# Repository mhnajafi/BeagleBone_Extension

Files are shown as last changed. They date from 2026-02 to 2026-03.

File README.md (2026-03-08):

# BeagleBone PLC Extension

This project focuses on transforming a BeagleBone Black into a Programmable Logic Controller (PLC) capable system. It includes PCB designs for Digital Input (DI), Digital Output (DO), and a Main Carrier board, along with simulation files.

## Project Structure

The repository is organized as follows:

- **PCB Design** (`PCB/`)
    - **Main/**: Contains the Altium Designer project files for the main carrier board that interfaces with the BeagleBone Black headers (P8/P9).
    - **DI/**: Design files for the Digital Input module.
    - **DO/**: Design files for the Digital Output module.

- **Simulation** (`DIO Simulate/`)
    - Contains Proteus simulation files (`.pdsprj`) to simulate the Digital I/O behavior before hardware implementation.

## Key Features

- **Modular Design**: Separate modules for Inputs and Outputs allowing for scalable IO.
- **BeagleBone Integration**: Designed to mount directly or interface via ribbon cables to the BeagleBone P8 and P9 headers.
- **Industrial Readiness**: Aimed at providing robust IO suitable for industrial control applications.

## Usage

1. **Hardware**: Start by reviewing the `PCB/Main` schematics. The manufacturing files (Gerbers) can be generated from the `.PcbDoc` files using Altium Designer.
2. **Simulation**: Open `DIO Simulate/DIO.pdsprj` in Proteus Design Suite to view and run the logic simulation.
3. **Reference**: Consult the pinout images in `Ignore/Doc/` when programming the IO pins on the BeagleBone.

## Gallery

### Main Carrier Board
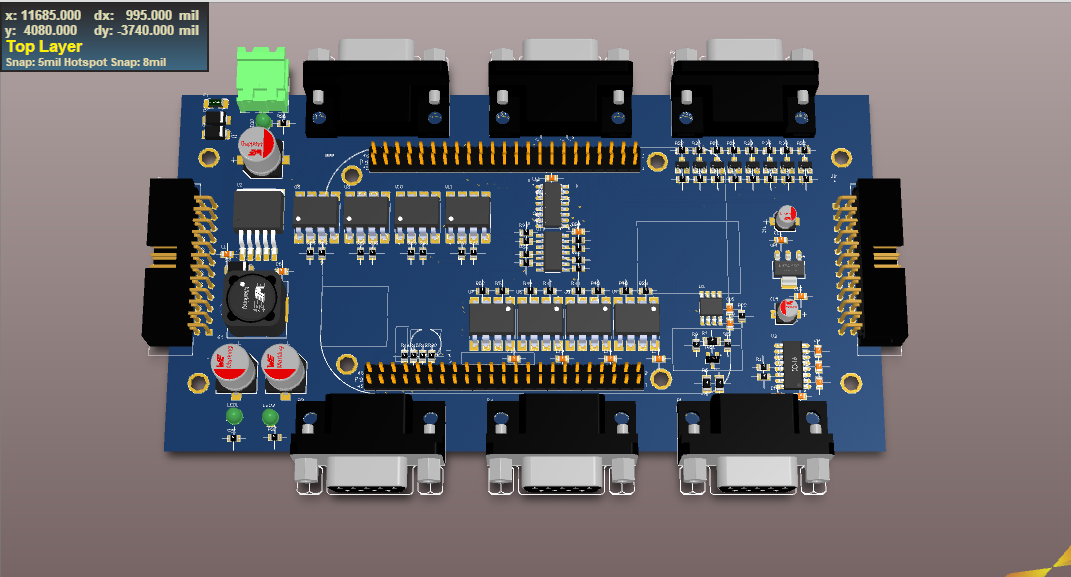
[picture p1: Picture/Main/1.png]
Main Board 1

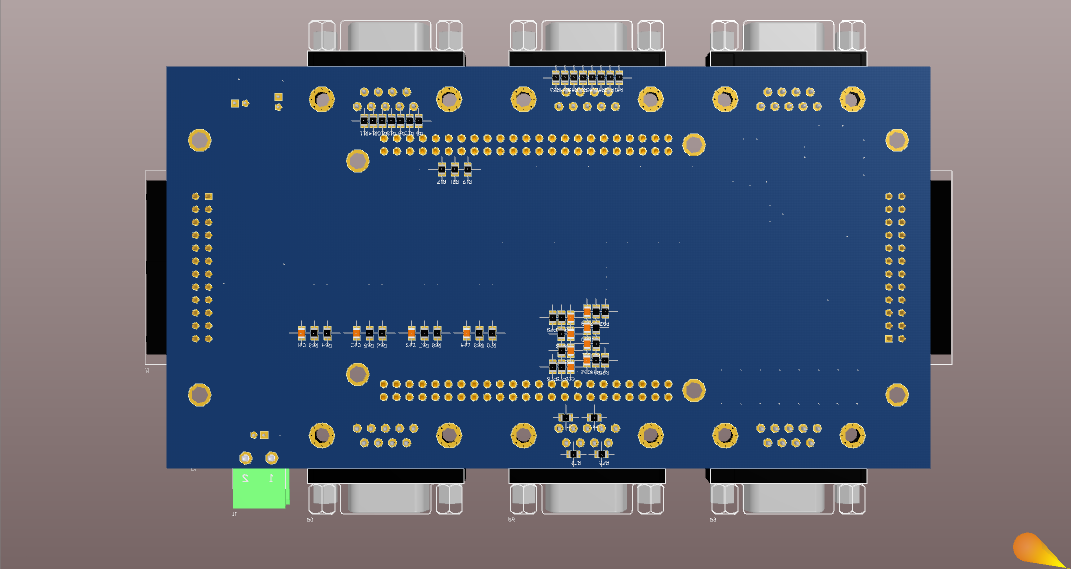
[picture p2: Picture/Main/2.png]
Main Board 2

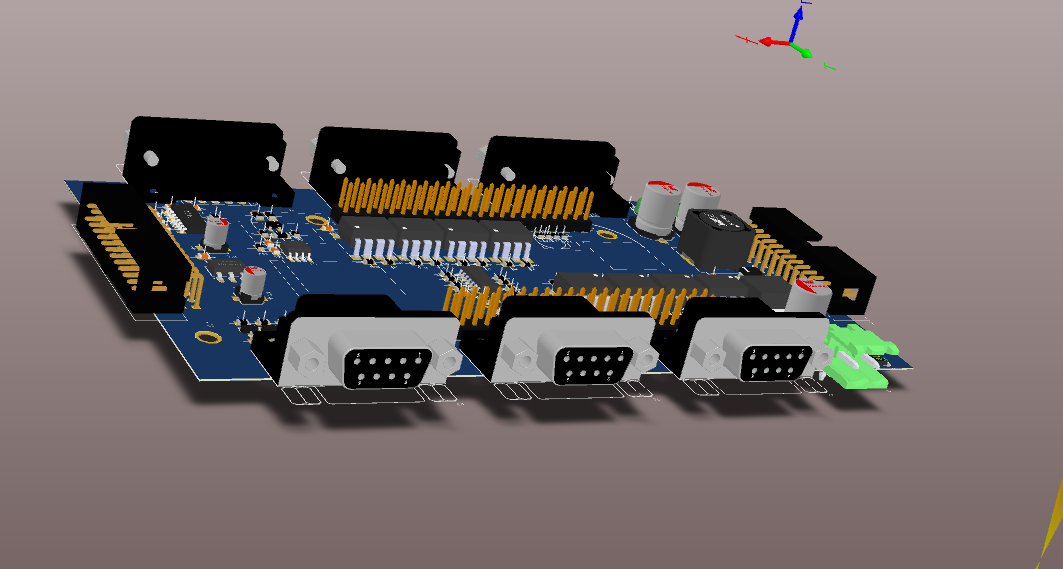
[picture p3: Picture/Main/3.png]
Main Board 3


### Digital Input Module
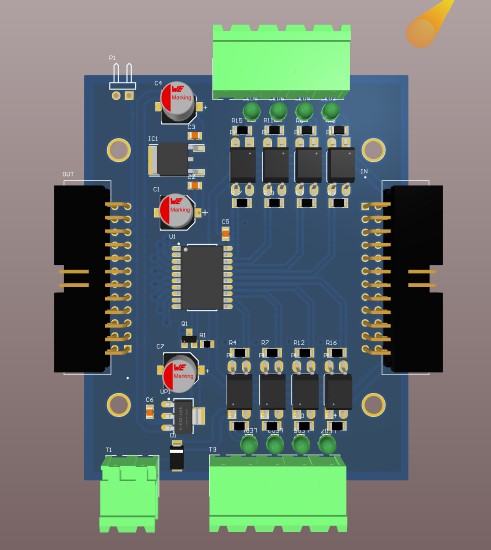
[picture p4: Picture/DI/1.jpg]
DI Module 1

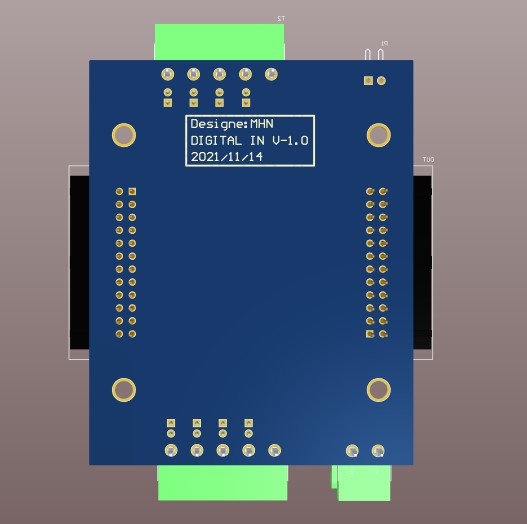
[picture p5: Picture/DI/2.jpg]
DI Module 2

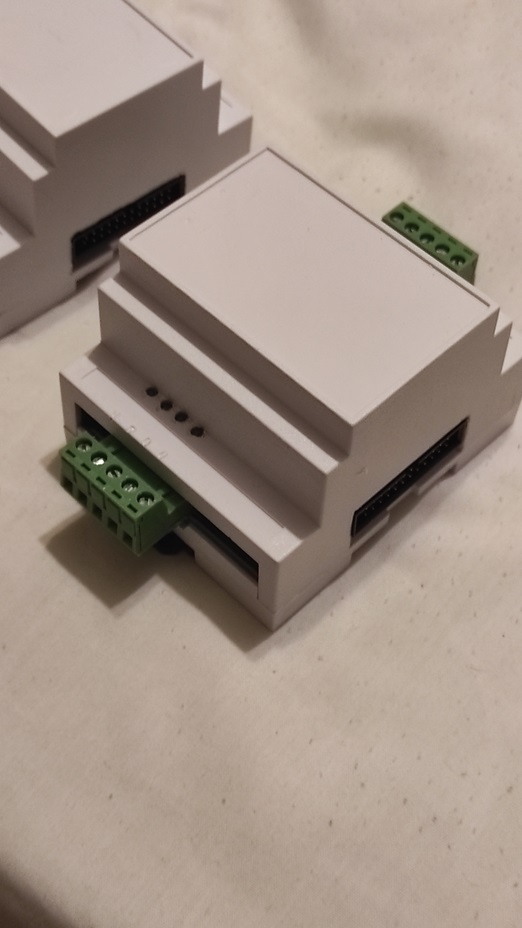
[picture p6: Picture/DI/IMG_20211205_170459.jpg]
DI Module Real


### Digital Output Module
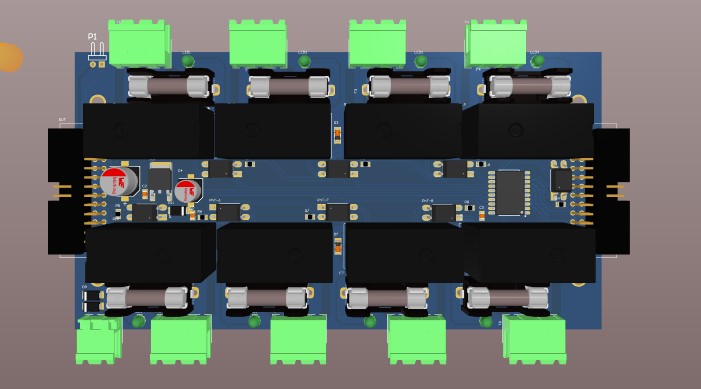
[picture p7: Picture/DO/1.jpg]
DO Module 1

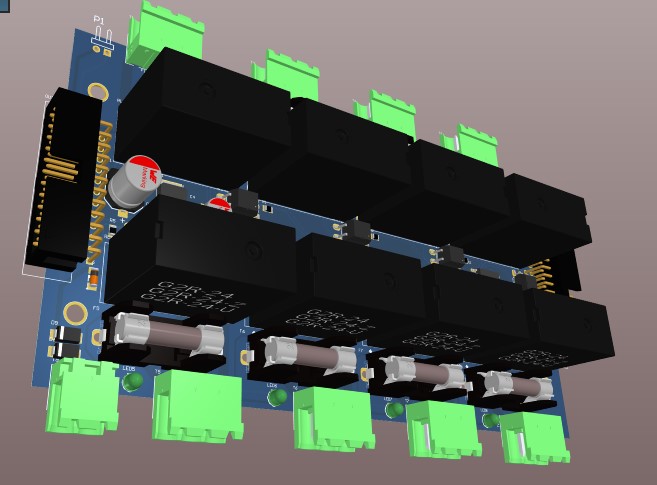
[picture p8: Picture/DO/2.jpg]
DO Module 2

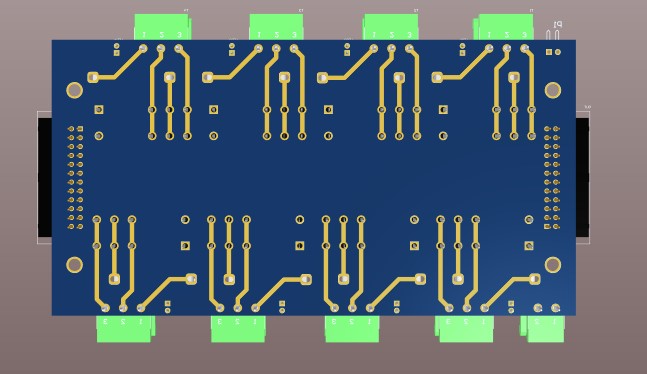
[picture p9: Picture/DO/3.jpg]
DO Module 3


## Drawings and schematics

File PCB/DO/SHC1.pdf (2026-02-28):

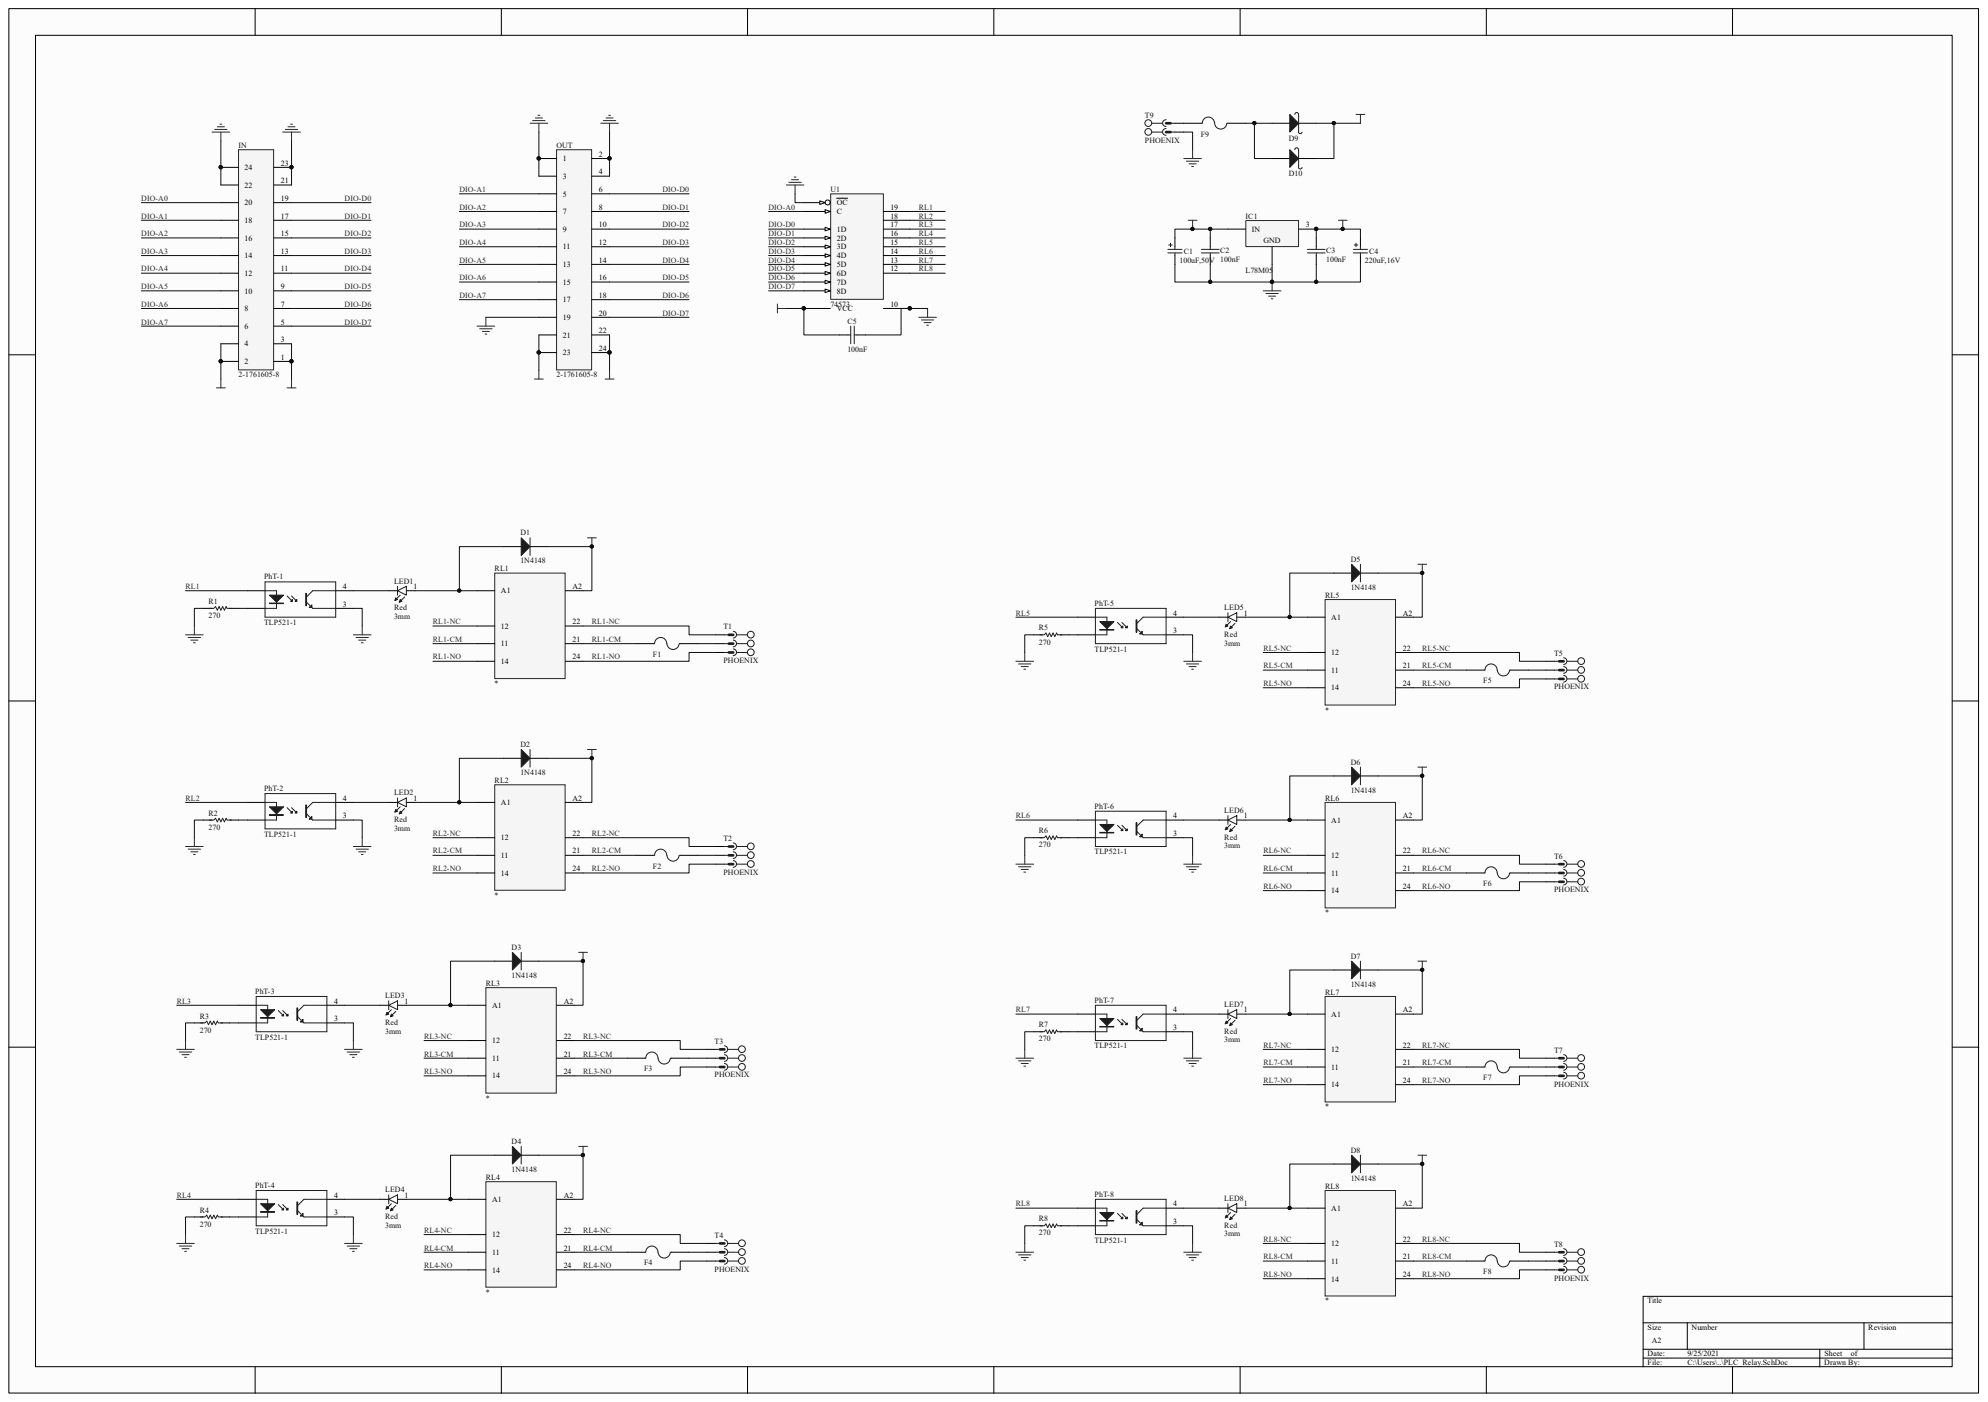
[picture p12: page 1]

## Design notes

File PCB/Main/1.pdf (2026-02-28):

# Beagle Bone Black

Expansion_Left | Expansion_Right

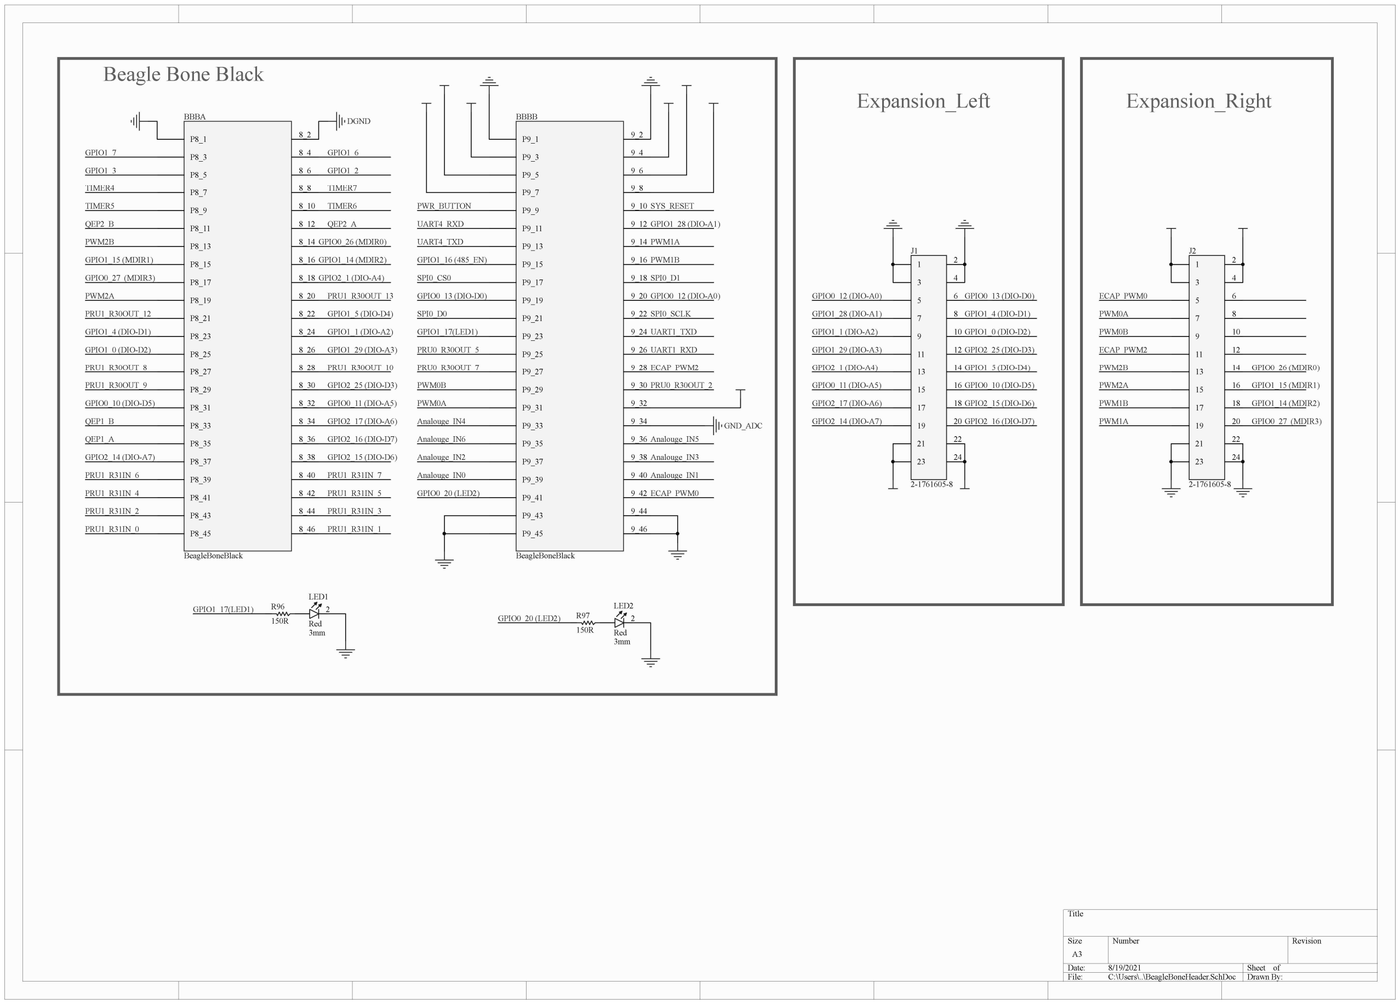
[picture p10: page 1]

Title

Size | Number | Revision
A3
Date: | 8/19/2021 | Sheet of
File: | C:\Users\..\BeagleBoneHeader.SchDoc | Drawn By:
P8_1 | 8_2
P8_3 | 8_4
P8_5 | 8_6
P8_7 | 8_8
P8_9 | 8_10
P8_11 | 8_12
P8_13 | 8_14
P8_15 | 8_16
P8_17 | 8_18
P8_19 | 8_20
P8_21 | 8_22
P8_23 | 8_24
P8_25 | 8_26
P8_27 | 8_28
P8_29 | 8_30
P8_31 | 8_32
P8_33 | 8_34
P8_35 | 8_36
P8_37 | 8_38
P8_39 | 8_40
P8_41 | 8_42
P8_43 | 8_44
P8_45 | 8_46

BBBA

BeagleBoneBlack

DGND

TIMER4

TIMER5

QEP2_B

PWM2B

PWM2A

PRU1_R30OUT_12

PRU1_R30OUT_8

PRU1_R30OUT_9

QEP1_B

QEP1_A

PRU1_R31IN_6

PRU1_R31IN_4

PRU1_R31IN_2

PRU1_R31IN_0

TIMER7

TIMER6

QEP2_A

PRU1_R30OUT_13

PRU1_R30OUT_10

PRU1_R31IN_7

PRU1_R31IN_5

PRU1_R31IN_3

PRU1_R31IN_1

P9_1 | 9_2
P9_3 | 9_4
P9_5 | 9_6
P9_7 | 9_8
P9_9 | 9_10
P9_11 | 9_12
P9_13 | 9_14
P9_15 | 9_16
P9_17 | 9_18
P9_19 | 9_20
P9_21 | 9_22
P9_23 | 9_24
P9_25 | 9_26
P9_27 | 9_28
P9_29 | 9_30
P9_31 | 9_32
P9_33 | 9_34
P9_35 | 9_36
P9_37 | 9_38
P9_39 | 9_40
P9_41 | 9_42
P9_43 | 9_44
P9_45 | 9_46

BBBB

BeagleBoneBlack

PWR_BUTTON

UART4_RXD

UART4_TXD

GPIO1_16 (485_EN)

SPI0_CS0

SPI0_D0

PRU0_R30OUT_5

PRU0_R30OUT_7

PWM0B

PWM0A

Analouge_IN4

Analouge_IN6

Analouge_IN2

Analouge_IN0

SYS_RESET

PWM1B

ECAP_PWM2

PRU0_R30OUT_2

Analouge_IN1

ECAP_PWM0

PWM1A

SPI0_D1

UART1_TXD

UART1_RXD

SPI0_SCLK

Analouge_IN5

Analouge_IN3

GND_ADC

GPIO1_7

GPIO1_3

GPIO1_6

GPIO1_2

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
11 12

13 14

15 16

17 18

19 20

21 22

23 24

J1

2-1761605-8

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
11 12

13 14

15 16

17 18

19 20

21 22

23 24

J2

2-1761605-8

PWM1A

PWM1B

GPIO1_17(LED1)

ECAP_PWM2

PWM0B

PWM0A

ECAP_PWM0

PWM2B

PWM2A

GPIO0_20 (LED2)

GPIO0_26 (MDIR0)

GPIO1_15 (MDIR1)

GPIO1_14 (MDIR2)

GPIO0_27 (MDIR3)

GPIO0_26 (MDIR0)

GPIO1_15 (MDIR1) | GPIO1_14 (MDIR2)

GPIO0_27 (MDIR3)

GPIO1_28 (DIO-A1)

GPIO0_13 (DIO-D0) | GPIO0_12 (DIO-A0)

GPIO2_1 (DIO-A4)

GPIO1_4 (DIO-D1)

GPIO1_5 (DIO-D4)

GPIO1_0 (DIO-D2)

GPIO1_1 (DIO-A2)

GPIO2_25 (DIO-D3)

GPIO1_29 (DIO-A3)

GPIO0_10 (DIO-D5) | GPIO0_11 (DIO-A5)
| GPIO2_17 (DIO-A6)

GPIO2_14 (DIO-A7)

GPIO2_16 (DIO-D7)

GPIO2_15 (DIO-D6)

2
Red
3mm

LED1

150R

R96
2
Red
3mm

LED2

150R

GPIO0_20 (LED2) R97

GPIO1_17(LED1)

GPIO0_11 (DIO-A5) | GPIO0_10 (DIO-D5)
GPIO2_14 (DIO-A7) | GPIO2_16 (DIO-D7)
GPIO2_17 (DIO-A6) | GPIO2_15 (DIO-D6)

GPIO1_29 (DIO-A3)

GPIO2_1 (DIO-A4) | GPIO1_5 (DIO-D4)

GPIO1_1 (DIO-A2)

GPIO2_25 (DIO-D3)

GPIO1_0 (DIO-D2)

GPIO1_28 (DIO-A1) | GPIO1_4 (DIO-D1)
GPIO0_12 (DIO-A0) | GPIO0_13 (DIO-D0)

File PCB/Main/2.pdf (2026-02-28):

# Power

# HighSpeed OUT

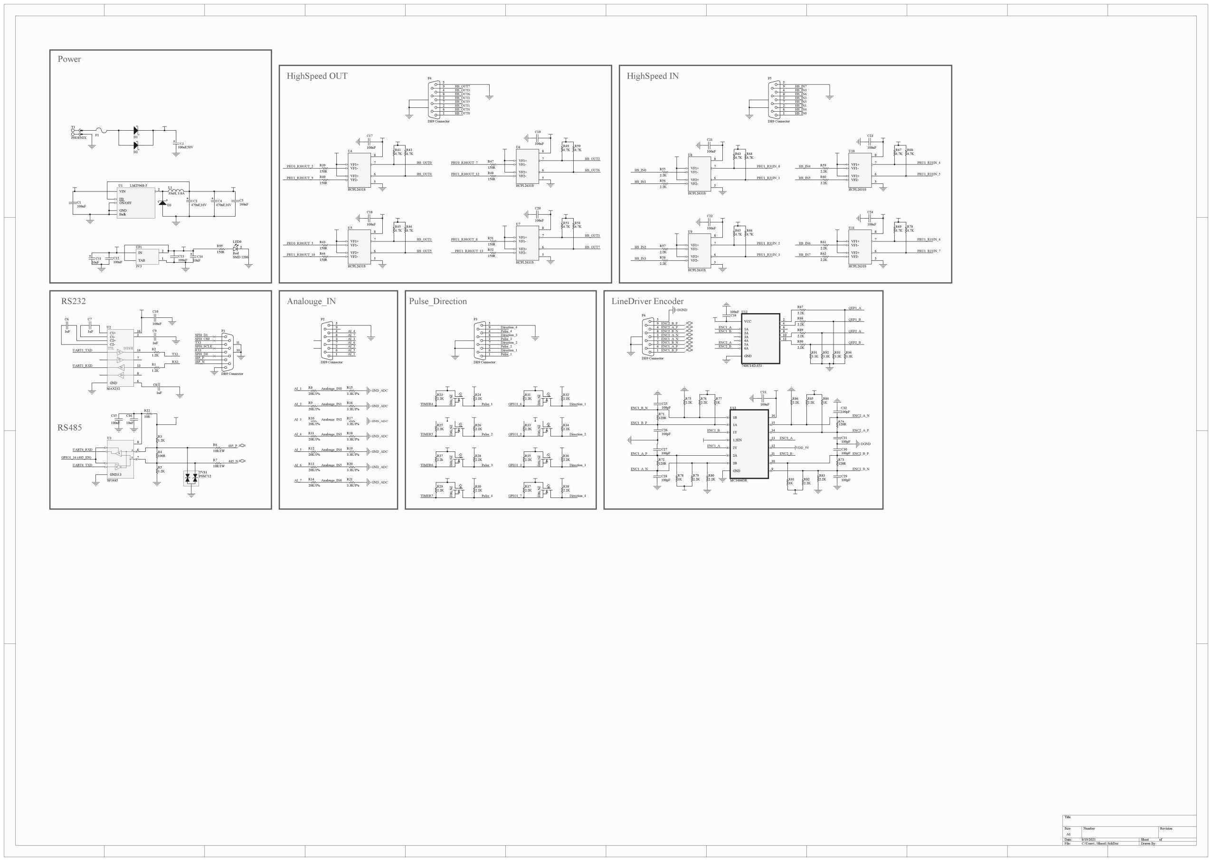
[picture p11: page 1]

Title

Size | Number | | Revision
A1
Date: | 8/19/2021 | Sheet | of
File: | C:\Users\..\Sheet1.SchDoc | Drawn By:

L1
33uH, 3.8A

2

Bulk

GND

ON/OFF

FB

VIN

U1 LM2596S-5

100nF

C5
100nF

C1
D3

D1

D2

C2
100uF,50V

F1

T1

PHOENIX

C3
470uF,16V

C4
470uF,16V

UART1_TXD

UART1_RXD

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
100nF

C10

1.2K

R1

1.2K

R2

IN | 2

### 1 TAB

UP1

3V3

100nF

C11 | C12
10uF | 100nF
C13 | C14
10uF

485_P
485_N

TX1

RX1

11

10

P1

DB9 Connector

8

6

7

GND3.3

D

R

A

B

U3

SP3485

UART4_RXD

UART4_TXD

GPIO1_16 (485_EN)

TVS1
PSM712

485_P

485_N

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
### 2 RS232 TTL

U2

MAX232

100nF

C15

10uF

C16

1.2K

R3

100R

R4

1.2K

R5

10R/1W

R6

10R/1W

R7

10R

R22
RS485

RS232

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
DB9 Connector

AI_4

AI_3
AI_6
AI_2
AI_5
AI_1
AI_1 | GND_ADC
20K/1%

R8
3.3K/1%
Analouge_IN0 | R15
AI_2 | GND_ADC
20K/1%

R9
3.3K/1%
Analouge_IN1 | R16
AI_3 | GND_ADC
20K/1%

R10
3.3K/1%
Analouge_IN2 | R17
AI_4 | GND_ADC
20K/1%

R11
3.3K/1%
Analouge_IN3 | R18
AI_5 | GND_ADC
20K/1%

R12
3.3K/1%
Analouge_IN4 | R19
AI_6 | GND_ADC
20K/1%

R13
3.3K/1%
Analouge_IN5 | R20
AI_7 | GND_ADC
20K/1%

R14
3.3K/1%
Analouge_IN6 | R21 | Q12N7002 2.2K
R23
2.2K

R24

TIMER4 | Pulse_1 Q22N7002 2.2K

R25
2.2K

R26

TIMER5 | Pulse_2 Q32N7002 2.2k

R27
2.2K

R28

TIMER6 | Pulse_3 Q42N7002 2.2K

R29
2.2K

R30

TIMER7 | Pulse_4 | Q52N7002 2.2K
R31
2.2K

R32

GPIO1_6 | Direction_1 Q62N7002 2.2K

R33
2.2K

R34

GPIO1_2 | Direction_2 Q72N7002 2.2K

R35
2.2K

R36

GPIO1_3 | Direction_3 Q82N7002 2.2K

R37
2.2K

R38

GPIO1_7 | Direction_4

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
DB9 Connector

Pulse_4
Direction_3
Pulse_3
Direction_2
Pulse_2
Direction_1
Pulse_1

Direction_4

AI_7

Analouge_IN | Pulse_Direction

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
DB9 Connector

HS_OUT3
HS_OUT6
HS_OUT2
HS_OUT5
HS_OUT1
HS_OUT4
HS_OUT0

HS_OUT7

VF1+
VF1-

VF2+
VF2-

8

7

6

5

U4

HCPL2631S

PRU0_R30OUT_2
150R

R39

150R

R40

4.7K

R41
4.7K

R42

HS_OUT0

100nF

C17

VF1+
VF1-

VF2+
VF2-

8

7

6

5

U5

HCPL2631S

150R

R43

150R

R44

4.7K

R45
4.7K

R46 100nF

C18

VF1+
VF1-

VF2+
VF2-

8

7

6

5

U6

HCPL2631S

150R

R47

150R

R48

4.7K

R49
4.7K

R50 100nF

C19

VF1+
VF1-

VF2+
VF2-

8

7

6

5

U7

HCPL2631S

150R

R51

PRU1_R30OUT_13
150R

R52

4.7K

R53
4.7K

R54

HS_OUT7

100nF

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
DB9 Connector

HS_IN3
HS_IN6
HS_IN2
HS_IN5
HS_IN1
HS_IN4
HS_IN0

HS_IN7

VF1+
VF1-

VF2+
VF2-

8

7

6

5

U8

HCPL2631S

2.2K

R55

2.2K

R56

4.7K

R63
4.7K

R64 100nF

C21

VF1+
VF1-

VF2+
VF2-

8

7

6

5

U9

HCPL2631S

2.2K

R57

2.2K

R58

4.7K

R65
4.7K

R66 100nF

C22

VF1+
VF1-

VF2+
VF2-

8

7

6

5

U10

HCPL2631S

2.2K

R59

2.2K

R60

4.7K

R67
4.7K

R68 100nF

C23

VF1+
VF1-

VF2+
VF2-

8

7

6

5

U11

HCPL2631S

2.2K

R61

2.2K

R62

4.7K

R69
4.7K

R70 100nF

C24

# HighSpeed IN

HS_IN2

HS_IN3

HS_IN1

HS_IN0

HS_IN7

HS_IN6

HS_IN5

PRU1_R31IN_0 | HS_IN4

PRU1_R31IN_1

PRU1_R31IN_2

PRU1_R31IN_3

PRU1_R31IN_4

PRU1_R31IN_6

PRU1_R31IN_7

PRU1_R31IN_5

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
DB9 Connector

DGND

ENC1_B_P

ENC1_A_P

ENC1_B_N

ENC1_A_N

ENC2_A_N

ENC2_B_N

ENC2_A_P

ENC2_B_P

ENC1_B_N

ENC1_B_P

ENC1_A_N

ENC1_A_P

ENC2_B_N

ENC2_B_P

ENC2_A_P

ENC2_A_N

1,2EN

1A

2A

2B

2Y | 12

10

14

13

15

16 1B

1Y

9

11

GND

U12

MC3486DR

100pF

C25

100pF

C26

100pF

C27

100pF

C28
100pF

C29

100pF

C30

100pF

C31

100pF

C32

DGND

120R

R72

120R

R71

120R

R74

120R

R73

ENC1_B

ENC1_A

ENC2_B

ENC2_A

VDD_5V

2.2K

R75
2.2K

R76
1K

R77
2.2K

R86
2.2K

R85
1K

R84

2.2K

R83

2.2K

R82
1K
2.2K | R81

R80
2.2K

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
74HC14D,653

ENC1_A
ENC1_B

ENC2_A
ENC2_B

100nF

C33

100nF
C34

# LineDriver Encoder

QEP1_A

QEP1_B

QEP2_A

QEP2_B

2.2K

R87

2.2K

R88

2.2K

R89

2.2K

R90

3.3K

R91
3.3K

R92
3.3K

R93
3.3K

R94

HS_OUT3
PRU1_R30OUT_8

HS_OUT2

HS_OUT6
PRU1_R30OUT_12

PRU0_R30OUT_7

HS_OUT5
PRU1_R30OUT_10

HS_OUT1
PRU0_R30OUT_5

PRU1_R30OUT_9

HS_OUT4

2
Red
SMD 1206

LED0

150R

R95

SPI0_D0

SPI0_SCLK

SPI0_CS0

SPI0_D1
